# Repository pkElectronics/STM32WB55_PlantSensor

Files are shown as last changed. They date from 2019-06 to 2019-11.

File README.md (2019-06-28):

# STM32WB55_PlantSensor
Project goal (for the first stage) is to develop an IOT System based on the STM32WB SoC to monitor soil and air Moisture as well as environment temperature.
Therefore several components will be developed including a battery powered sensor to stick into your flower pots and a base station to display and log the measurements from the sensors. 
Communication between the sensors and the base will be done via bluetooth mesh. Later more kinds of sensors may be developed as well.

All Hardware Design Files licensed under CC BY-NC 4.0 

https://creativecommons.org/licenses/by-nc/4.0/legalcode

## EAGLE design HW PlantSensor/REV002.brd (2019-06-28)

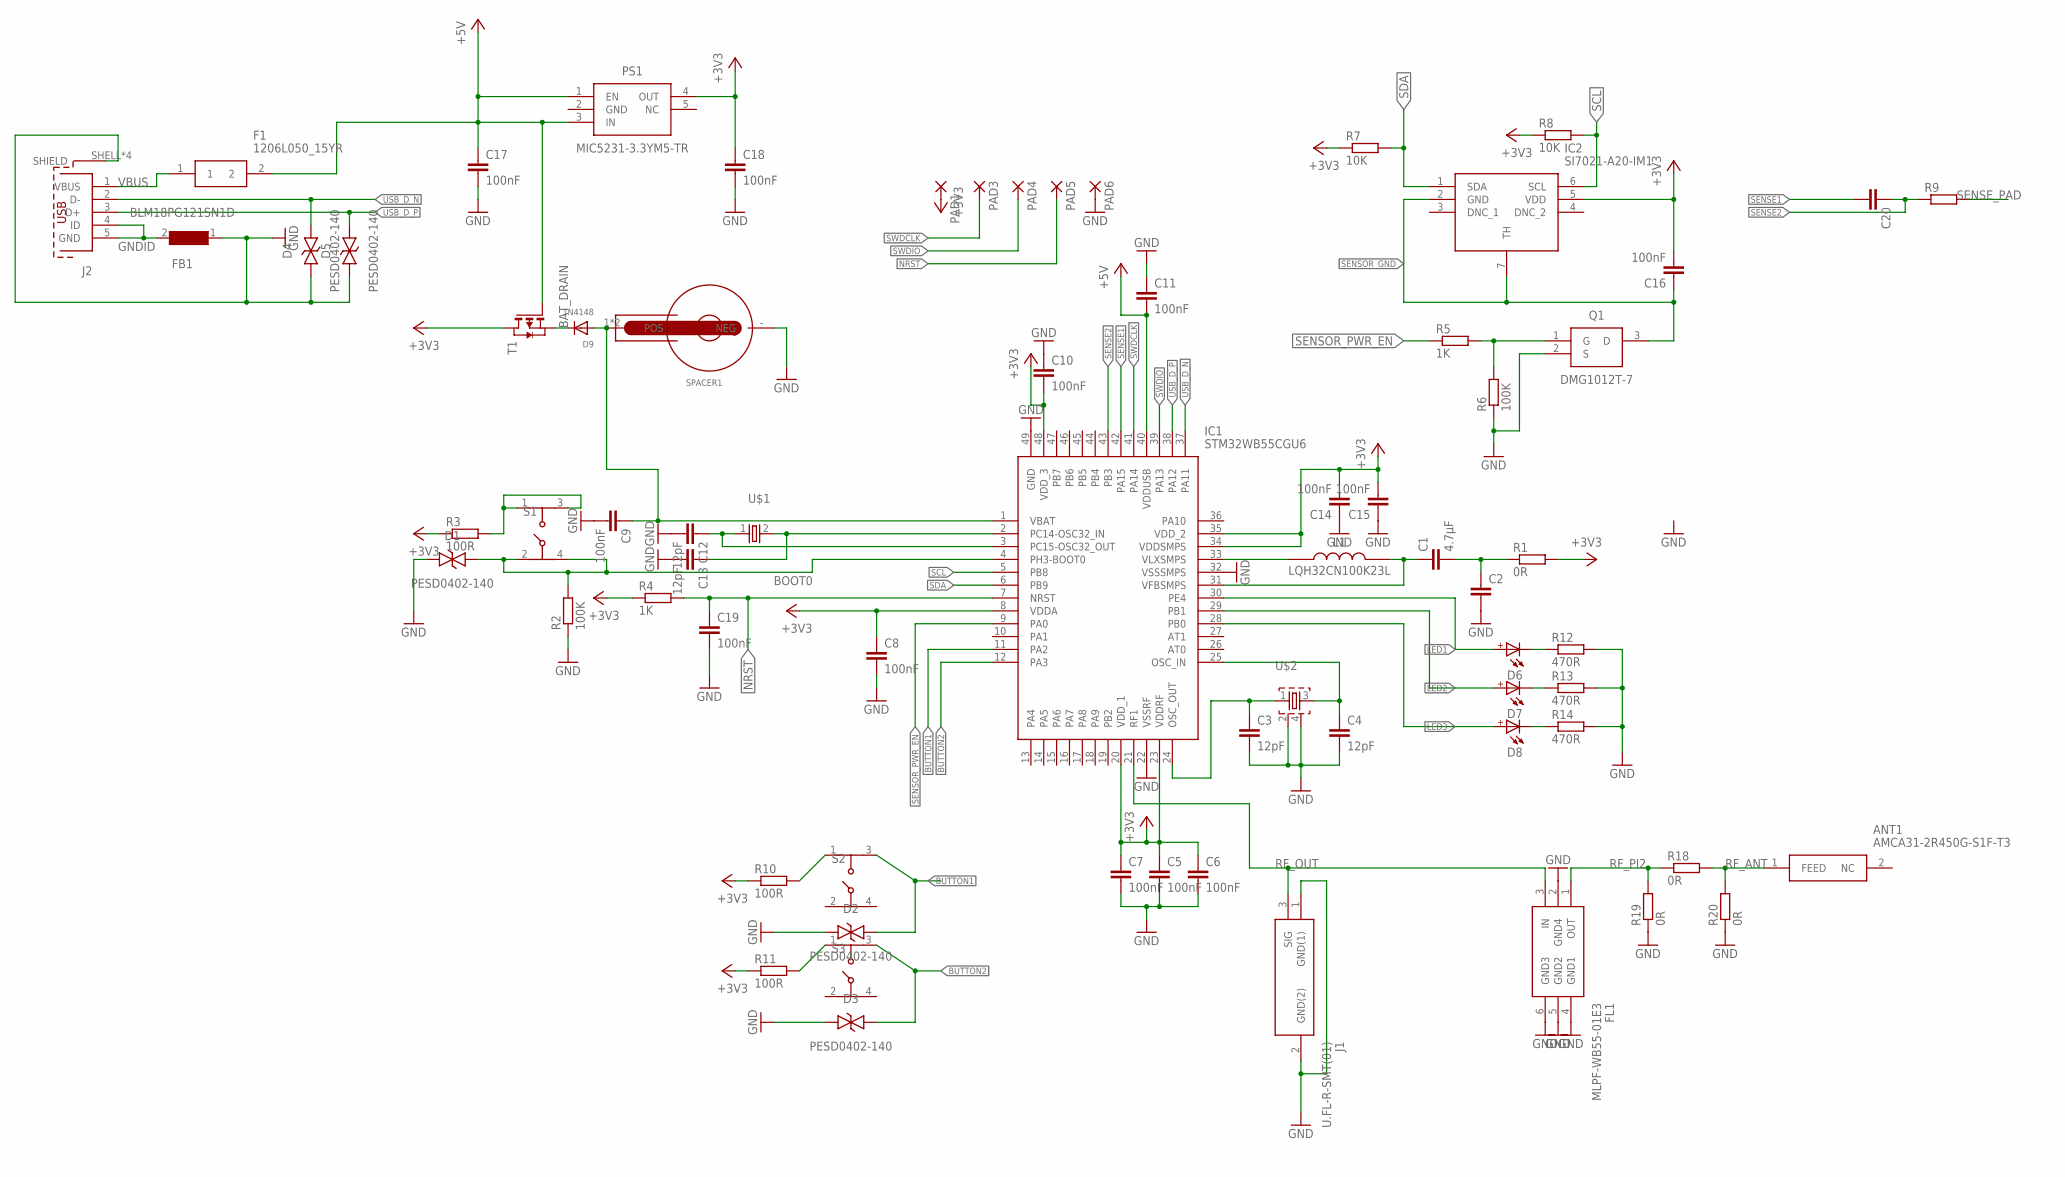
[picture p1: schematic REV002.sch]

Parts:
ANT1: AMCA31-2R450G-S1F-T3; ANTC3216X140N
C1: 4.7µF; C1210K
C2, C20: C-EUC0402K; C0402K
C3, C4, C12, C13: 12pF; C0402K
C5, C6, C7, C8, C9, C10, C11, C14, C15, C16, C17, C18, C19: 100nF; C0402K
D1, D2, D3, D4, D5: PESD0402-140; DIONC1005X43N
D6, D7, D8: WL-SMCD_0603_150060BS55040; WL-SMCD_0603
D9: 1N4148; SOD-323F
F1: 1206L050_15YR; FUSC3216X75N
FB1: BLM18PG121SN1D; BEADC1608X95N
FL1: MLPF-WB55-01E3; MLPFWB5501E3
IC1: STM32WB55CGU6; QFN50P700X700X65-49N
IC2: SI7021-A20-IM1; SON100P300X300X121-7N
J1: U.FL-R-SMT(01)
J2: 629105136821
L1: LQH32CN100K23L; INDPM3225X220N
PAD1, PAD3, PAD4, PAD5, PAD6: SMD2; SMD1,27-2,54
PS1: MIC5231-3.3YM5-TR; SOT95P270X145-5N
Q1: DMG1012T-7; SOT50P160X80-3N
R1, R18, R19, R20: 0R; R0402
R2, R6: 100K; R0402
R3, R10, R11: 100R; R0402
R4, R5: 1K; R0402
R7, R8: 10K; R0402
R9: R-EU_R0402; R0402
R12, R13, R14: 470R; R0402
S1, S2, S3: 434153017835
SPACER1: WA-BCMC_SMT_79523141; 79523141
T1: PMOSSOT23; SOT-23
U$1: XTAL_32KHZ; XTAL_3215_N
U$2: XTAL_32MHZ; BT-XTAL_2016_N

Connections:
+3V3: C5.1, C6.1, C7.1, C8.1, C10.2, C14.2, C15.2, C16.2, C18.1, IC1.8 (VDDA), IC1.20 (VDD_1), IC1.23 (VDDRF), IC1.34 (VDDSMPS), IC1.35 (VDD_2), IC1.48 (VDD_3), IC2.5 (VDD), PAD1.1, PS1.4 (OUT), R1.2, R3.1, R4.1, R7.1, R8.1, R10.1, R11.1, T1.1 (D)
+5V: C11.2, C17.1, F1.2, IC1.40 (VDDUSB), PS1.1 (EN), PS1.3 (IN), T1.3 (G)
BAT+: C9.1, D9.A, IC1.1 (VBAT), SPACER1.1 (POS), SPACER1.2 (POS)
BAT_DRAIN: D9.C, T1.2 (S)
BOOT0: D1.2 (A), IC1.4 (PH3-BOOT0), R2.2, S1.2 (3), S1.4
BOOT0_R: R3.2, S1.1, S1.3 (2)
BUTTON1: D2.2 (A), IC1.11 (PA2), S2.3 (2)
BUTTON1_R: R10.2, S2.1
BUTTON2: D3.2 (A), IC1.12 (PA3), S3.3 (2)
BUTTON2_R: R11.2, S3.1
GND: C2.2, C3.2, C4.2, C5.2, C6.2, C7.2, C8.2, C9.2, C10.1, C11.1, C12.2, C13.2, C14.1, C15.1, C17.2, C18.2, C19.2, D1.1 (K), D2.1 (K), D3.1 (K), D4.1 (K), D5.1 (K), FB1.1, FL1.2 (GND4), FL1.4 (GND1), FL1.5 (GND2), FL1.6 (GND3), IC1.22 (VSSRF), IC1.32 (VSSSMPS), IC1.49 (GND), J1.1 (GND(1)), J1.2 (GND(2)), J2.SHELL (SHIELD), J2.SHELL1 (SHIELD), J2.SHELL2 (SHIELD), J2.SHELL3 (SHIELD), PAD6.1, Q1.2 (S), R2.1, R6.1, R12.2, R13.2, R14.2, R19.1, R20.1, SPACER1.- (NEG), U$2.2, U$2.4
GNDID: FB1.2, J2.4 (ID), J2.5 (GND)
LED1: D6.2 (A), IC1.30 (PE4)
LED1_R: D6.1 (C), R12.1
LED2: D7.2 (A), IC1.29 (PB1)
LED2_R: D7.1 (C), R13.1
LED3: D8.2 (A), IC1.28 (PB0)
LED3_R: D8.1 (C), R14.1
unnamed: C13.1, IC1.2 (PC14-OSC32_IN), U$1.2
unnamed: C12.1, IC1.3 (PC15-OSC32_OUT), U$1.1
NRST: C19.1, IC1.7 (NRST), PAD5.1, R4.2
OSC_IN: C4.1, IC1.25 (OSC_IN), U$2.3
OSC_OUT: C3.1, IC1.24 (OSC_OUT), U$2.1
RF_ANT: ANT1.1 (FEED), R18.2, R20.2
RF_OUT: FL1.3 (IN), IC1.21 (RF1), J1.3 (SIG)
RF_PI2: FL1.1 (OUT), R18.1, R19.2
SCL: IC1.5 (PB8), IC2.6 (SCL), R8.2
SDA: IC1.6 (PB9), IC2.1 (SDA), R7.2
SENSE1: C20.2, IC1.42 (PA15)
SENSE2: C20.1, IC1.43 (PB3), R9.1
SENSE_PAD: R9.2
SENSOR_GATE: Q1.1 (G), R5.2, R6.2
SENSOR_GND: C16.1, IC2.2 (GND), IC2.7 (TH), Q1.3 (D)
SENSOR_PWR_EN: IC1.9 (PA0), R5.1
SMPS: C1.2, C2.1, R1.1
SWDCLK: IC1.41 (PA14), PAD3.1
SWDIO: IC1.39 (PA13), PAD4.1
USB_D_N: D4.2 (A), IC1.37 (PA11), J2.2 (D-)
USB_D_P: D5.2 (A), IC1.38 (PA12), J2.3 (D+)
VBUS: F1.1, J2.1 (VBUS)
VFBSMPS: C1.1, IC1.31 (VFBSMPS), L1.2
VLXSMPS: IC1.33 (VLXSMPS), L1.1

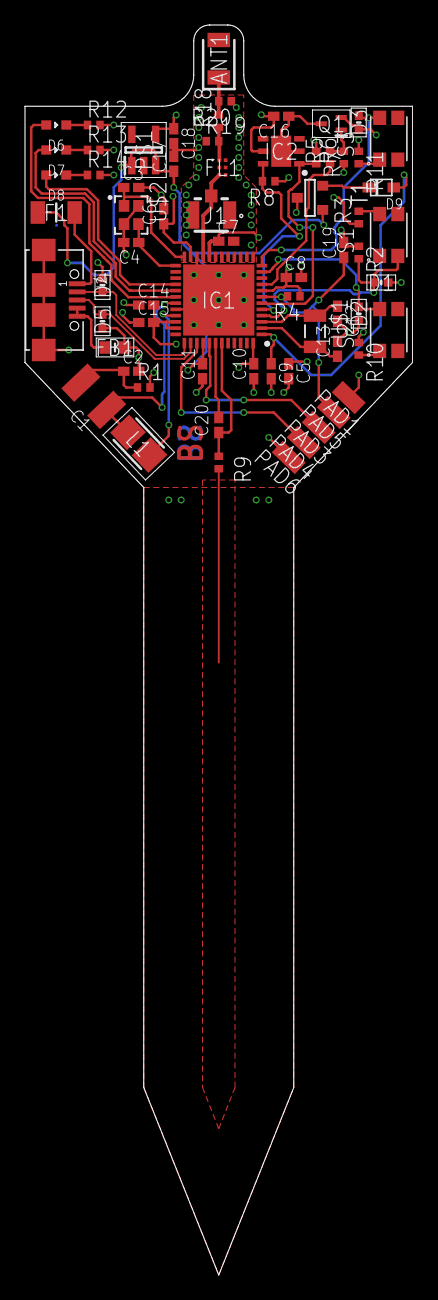
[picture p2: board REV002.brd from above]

Board: 4 copper layers, 31.0 x 100.0 mm, 69 parts (1 on the bottom side), 41 nets.

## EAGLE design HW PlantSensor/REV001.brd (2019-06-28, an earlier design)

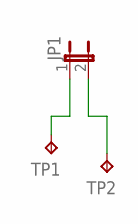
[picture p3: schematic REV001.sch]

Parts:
JP1: JP1E; JP1
TP1, TP2: TPTP06SQ; TP06SQ

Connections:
1: JP1.1, TP1.TP
2: JP1.2, TP2.TP

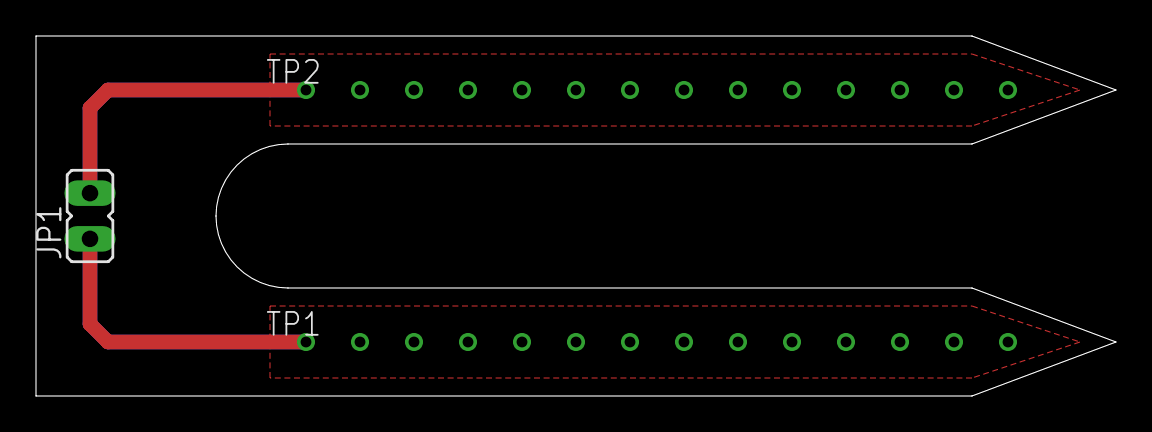
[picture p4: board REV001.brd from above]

Board: 2 copper layers, 60.0 x 20.0 mm, 3 parts (0 on the bottom side), 2 nets.

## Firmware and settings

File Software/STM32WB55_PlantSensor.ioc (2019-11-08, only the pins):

Mcu.UserName=STM32WB55CGUx
PA0.GPIO_Label=SENSOR_PWR
PA0.Signal=GPIO_Output
PA11.Signal=USB_DM
PA12.Signal=USB_DP
PA13.Signal=SYS_JTMS-SWDIO
PA14.Signal=SYS_JTCK-SWCLK
PA15.GPIO_Label=SENSE1
PA15.Signal=GPIO_Input
PA2.GPIO_Label=BUTTON1
PA2.Signal=GPIO_Output
PA3.GPIO_Label=BUTTON2
PA3.Signal=GPIO_Output
PB0.GPIO_Label=LED3
PB0.Signal=GPIO_Output
PB1.GPIO_Label=LED2
PB1.Signal=GPIO_Output
PB3.GPIO_Label=SENSE2
PB3.Signal=GPIO_Input
PB8.Signal=I2C1_SCL
PB9.Signal=I2C1_SDA
PC14-OSC32_IN.Signal=RCC_OSC32_IN
PC15-OSC32_OUT.Signal=RCC_OSC32_OUT
PE4.GPIO_Label=LED1
PE4.Signal=GPIO_Output

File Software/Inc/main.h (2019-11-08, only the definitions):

#define SENSOR_PWR_Pin GPIO_PIN_0
#define SENSOR_PWR_GPIO_Port GPIOA
#define BUTTON1_Pin GPIO_PIN_2
#define BUTTON1_GPIO_Port GPIOA
#define BUTTON2_Pin GPIO_PIN_3
#define BUTTON2_GPIO_Port GPIOA
#define LED3_Pin GPIO_PIN_0
#define LED3_GPIO_Port GPIOB
#define LED2_Pin GPIO_PIN_1
#define LED2_GPIO_Port GPIOB
#define LED1_Pin GPIO_PIN_4
#define LED1_GPIO_Port GPIOE
#define SENSE1_Pin GPIO_PIN_15
#define SENSE1_GPIO_Port GPIOA
#define SENSE2_Pin GPIO_PIN_3
#define SENSE2_GPIO_Port GPIOB

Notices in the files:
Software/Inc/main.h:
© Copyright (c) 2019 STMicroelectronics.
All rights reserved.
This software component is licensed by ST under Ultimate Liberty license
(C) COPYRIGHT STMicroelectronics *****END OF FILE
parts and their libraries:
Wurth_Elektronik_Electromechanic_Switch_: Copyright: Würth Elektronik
